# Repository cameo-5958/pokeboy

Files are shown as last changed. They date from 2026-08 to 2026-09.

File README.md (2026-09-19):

# Pokeboy

Game Boy handheld with its own emulator and a Gen 1 Pokemon battle AI that runs
on the device. No ROMs in here, bring your own.

## How the AI works

Trainers are driven by a small transformer with a GRU on top. It is integer
only: int8 weights, int16 hidden state, no floats on the device.

The patched ROM runs an unused opcode (`$DB`, `$EB`, `$EC`) wherever the game
would normally pick a trainer's move. The emulator traps it, reads the battle
out of WRAM, runs the model and writes the choice back.

One decision is too slow for a single frame on the Cortex-A8, so the model is
cut into small steps (one GEMM block, one attention head, one GRU step) and the
scheduler fits them in between frames. `ai/models/pep_int.py` is the reference
and the C++ in `pkai/` has to match it bit for bit. There is a test for that.

## Layout

- `gameboy/` emulator core, tests, tools
- `emulator/` frontends: linux, headless, win32
- `pkai/` battle AI
- `pred-patch/` pokered with the opcodes the AI hooks into
- `ai/` simulator, training, weight export
- `buildroot/` device image (PocketBeagle / OSD3358)
- `hardware/` KiCad project
- `app/` Expo app
- `backend/` API for ROMs, mods and cartridge metadata

## Build

```sh
# core, C++17
cmake -S gameboy -B build -DCMAKE_BUILD_TYPE=Release -DPKAI_BUILD_ROM=OFF
cmake --build build -j
build/gbemu_headless game.gb 1800 out.bmp

# patched ROM (needs rgbds) and AI
pred-patch/build_ai.sh
cd ai && uv sync --group dev && sim/build_engine.sh && scripts/build_pkai.sh

# device image
buildroot/scripts/build-image.sh
buildroot/scripts/qemu/run-system.sh

# backend (:4000) and app
cd backend && npm install && npm run dev
cd app && npm install && npm start
```

Most of the `pkai` tests skip themselves until the patched ROM and the weights
have been built.

## License

MIT, see `LICENSE`. `pred-patch/` is the pret/pokered disassembly under its own
terms, see `pred-patch/THIRD_PARTY_NOTICES.md`.

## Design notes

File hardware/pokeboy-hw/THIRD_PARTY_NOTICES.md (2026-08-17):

# Third-party hardware notice

`Pokeboy.pretty/OSD335X-BGA-256.kicad_mod` is adapted from the PocketBeagle
hardware design published by BeagleBoard.org at
<https://github.com/beagleboard/pocketbeagle>.

PocketBeagle hardware design files are licensed under Creative Commons
Attribution 4.0 International (CC BY 4.0). Pokeboy modifications include the
footprint library name, value, board placement, net assignments, and escape
routing integration.

License: <https://creativecommons.org/licenses/by/4.0/>

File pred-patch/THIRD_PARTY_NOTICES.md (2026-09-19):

# Third-party notice

This directory is the pret/pokered disassembly, <https://github.com/pret/pokered>,
with the Pokeboy AI patch on top: the `$DB`/`$EB`/`$EC` opcodes and
`tools/generate_ai.py`. Everything else is upstream work under pret's terms.

The patch lives mostly in `engine/battle/ai_protocol.asm`, with call sites in
`engine/battle/core.asm`, `trainer_ai.asm` and `used_move_text.asm`, and a few
bytes of state in `ram/wram.asm`. To see all of it:

```sh
git diff a41af38 HEAD -- pred-patch
```

`a41af38` is the untouched upstream import.

The patch itself is MIT, same as the rest of Pokeboy; see `LICENSE` in the
parent repository.

Pokemon is © Nintendo / Creature Inc. / GAME FREAK inc. No ROM is distributed
here; `build_ai.sh` assembles one from this source on your machine.

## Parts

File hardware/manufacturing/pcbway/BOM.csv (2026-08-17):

Item | Qty | Designators | Value | Footprint | Manufacturer | Manufacturer Part Number | Assembly | Substitution note
1 | 1 | U1 | AM3358 + 1GB DDR3L | 21x21mm 256-BGA 1.27mm | Octavo Systems | OSD3358-1G-ISM | SMT BGA | No substitution; PCBWay to source (full turnkey); X-ray
2 | 1 | U2 | 1S Li-ion charger/power path | VQFN-16 | Texas Instruments | BQ24074RGT | SMT | No substitution
3 | 1 | U3 | 5V buck-boost | TPS63802 DLA10 | Texas Instruments | TPS63802DLAR | SMT | No substitution
4 | 1 | U4 | 3.3V buck | WSON-8 | Texas Instruments | TPS62162DSGR | SMT | No substitution
5 | 1 | U5 | LED boost | WSON-6 | Texas Instruments | TPS61165DRVR | SMT | No substitution
6 | 1 | U6 | I2S mono class-D | TQFN-16 | Analog Devices | MAX98357AETE+T | SMT | No substitution
7 | 1 | U7 | USB ESD | DRT-3 (SOT-5X3) 1.0x1.0mm | Texas Instruments | TPD2EUSB30DRTR | SMT | No substitution; DRT-3 land pattern not SOT-23
8 | 1 | J1 | Micro-USB B | 105017 footprint | Molex | 1050170001 | SMT | No substitution
9 | 1 | J9 | microSD push-push | 104031 footprint | Molex | 1040310811 | SMT | No substitution
10 | 4 | SW1 SW2 SW3 SW4 | D-pad tactile | Pokeboy EVQ-P1905M | Panasonic | EVQ-P1905M | SMT | No substitution
11 | 2 | SW5 SW6 | A/B tactile | Pokeboy B3AL-1001P | Omron | B3AL-1001P | SMT | No substitution
12 | 2 | SW7 SW8 | Start/Select tactile | Pokeboy EVQ-P2B02B | Panasonic | EVQ-P2B02B | SMT | No substitution
13 | 1 | Y1 | 24MHz crystal | 5.0x3.2mm 2-pad | CTS | 445A35A24M00000 | SMT | Verify lifecycle; PCBWay to source (full turnkey)
14 | 1 | L1 | 0.47uH | XFL4015 | Coilcraft | XFL4015-471MEC | SMT | No substitution without power review
15 | 1 | L2 | 2.2uH | NRS3012 | Taiyo Yuden | NRS3012T2R2MMGJ | SMT | Equivalent >=1.5A permitted
16 | 1 | L3 | 10uH | LQH43PN | Murata | LQH43PN100M26L | SMT | Equivalent >=1A permitted; 2.80 mm MAX height (Murata JELF243A-0093); low-profile alt Coilcraft XGL4040-103 (2.10 mm max) needs 4.0x4.0 land
17 | 2 | FB1 FB2 | 600ohm at 100MHz | 0402 | Murata | BLM15AG601SN1D | SMT | Equivalent permitted
18 | 1 | D1 | Red LED | 0402 | Lite-On | LTST-C191KRKT | SMT | Equivalent color/current permitted
19 | 1 | D2 | Green LED | 0402 | Lite-On | LTST-C191KGKT | SMT | Equivalent color/current permitted
20 | 1 | D3 | 60V Schottky | SOD-123F | Nexperia | PMEG6010CEH115 | SMT | Equal or better permitted
21 | 1 | C1 | 10nF 16V X7R | 0402 | Murata | GRM155R71C103KA88D | SMT | Equivalent permitted
22 | 5 | C2 C3 C4 C6 C10 | 10uF 10V X5R | 0402 | Murata | GRM155R61A106ME11D | SMT | No lower voltage
23 | 2 | C7 C8 | 22uF 10V X5R | 0402 | Murata | GRM158R61A226ME15D | SMT | MPN corrected: GRM155 case does not exist in 22uF/10V; GRM158 is the 0.8mm-tall 0402 on the same land
24 | 1 | C11 | 22uF 6.3V X5R | 0402 | Murata | GRM158R60J226ME15D | SMT | MPN corrected: GRM155 case not made in 22uF/6.3V; GRM158 tall 0402 | same land
25 | 9 | C5 C9 C12 C15 C21 C25 C26 C27 C105 | 100nF 16V X7R | 0402 | Murata | GRM155R71C104KA88D | SMT | Equivalent permitted
26 | 1 | C13 | 1uF 50V X5R | 0402 | Murata | GRM155R61H105KE11D | SMT | No lower voltage
27 | 1 | C14 | 4.7uF 10V X5R | 0402 | Murata | GRM155R61A475MEAAD | SMT | Equivalent permitted
28 | 1 | C16 | 220nF 10V X7R | 0402 | Murata | GRM155R71A224KA01D | SMT | Equivalent permitted
29 | 1 | C20 | 10uF 6.3V X5R | 0402 | Murata | GRM155R60J106ME15D | SMT | Equivalent permitted
30 | 2 | C22 C23 | 220pF 50V C0G | 0402 | Murata | GRM1555C1H221JA01D | SMT | Equivalent C0G permitted
31 | 1 | C24 | 1uF 10V X5R | 0402 | Murata | GRM155R61A105KE15D | SMT | Equivalent permitted
32 | 2 | C102 C103 | 18pF 50V C0G | 0402 | Murata | GRM1555C1H180JA01D | SMT | Match crystal load calculation
33 | 1 | C106 | 10uF 10V X5R | 0805 | Murata | GRM21BR61A106KE19L | SMT | Equivalent permitted
34 | 1 | R3 | 0ohm | 0402 | Yageo | RC0402JR-070RL | SMT | Was 10k VBUS divider top (Octavo UB1) - now 0ohm link. R1/R2 deleted in PROTO-B1: USB DP/DM are direct connections
35 | 2 | R10 R11 | 2.2kohm 1% | 0402 | Yageo | RC0402FR-072K2L | SMT | Equivalent permitted
36 | 8 | R31 R32 R104 R105 R106 R107 R108 R109 | 10kohm 1% | 0402 | Yageo | RC0402FR-0710KL | SMT | Equivalent permitted
37 | 8 | R12 R13 R17 R18 R20 R21 R23 R26 | 100kohm 1% | 0402 | Yageo | RC0402FR-07100KL | SMT | Equivalent permitted
38 | 1 | R14 | 806kohm 1% | 0402 | Yageo | RC0402FR-07806KL | SMT | Equivalent permitted
39 | 1 | R15 | 91kohm 1% | 0402 | Yageo | RC0402FR-0791KL | SMT | Equivalent permitted
40 | 1 | R16 | 187kohm 1% | 0402 | Yageo | RC0402FR-07187KL | SMT | Equivalent permitted
41 | 1 | R22 | 10ohm 1% | 0402 | Yageo | RC0402FR-0710RL | SMT | Equivalent permitted
42 | 4 | R27 R28 R29 R30 | 33ohm 1% | 0402 | Yageo | RC0402FR-0733RL | SMT | Equivalent permitted
43 | 2 | R33 R102 | 1Mohm 1% | 0402 | Yageo | RC0402FR-071ML | SMT | Equivalent permitted
44 | 1 | R34 | 330kohm 1% | 0402 | Yageo | RC0402FR-07330KL | SMT | Equivalent permitted
45 | 1 | R5 | 1.78kohm 1% | 0402 | Yageo | RC0402FR-071K78L | SMT | Equivalent permitted
46 | 1 | R6 | 3.09kohm 1% | 0402 | Yageo | RC0402FR-073K09L | SMT | Equivalent permitted
47 | 1 | R7 | 3.01kohm 1% | 0402 | Yageo | RC0402FR-073K01L | SMT | Equivalent permitted
48 | 1 | R8 | 46.4kohm 1% | 0402 | Yageo | RC0402FR-0746K4L | SMT | Equivalent permitted
49 | 1 | R19 | 0ohm | 0402 | Yageo | RC0402JR-070RL | DNP | Do not fit
50 | 1 | R9 | 10kohm | 0402 | Yageo | RC0402FR-0710KL | DNP | Do not fit
57 | 1 | R4 | 10kohm | 0402 | Yageo | RC0402FR-0710KL | DNP | Do not fit; was VBUS divider bottom - deleted so USB0_VBUS sees 5 V (Octavo UB1)
51 | 6 | RN1 RN2 RN3 RN4 RN5 RN6 | 4x22ohm | 4x0603 convex | Yageo | YC164-JR-0722RL | SMT | No substitution without SI review
52 | 4 | RN7 RN8 RN9 RN10 | 4x100kohm | 4x0603 convex | Yageo | YC164-JR-07100KL | SMT | Keep exact SYSBOOT pattern
53 | 1 | J5 | 39-pin 0.3mm bottom-contact FFC connector | EA_WF030_39S land pattern | DISPLAY VISIONS | EA WF030-39S | SMT | Board-mounted connector; must be placed by SMT
54 | 1 | J2 | Protected 1S LiPo with 10k NTC | Wire pads | User supplied | USER-SUPPLIED-LIPO-1S-NTC | OFF-BOARD | Polarity and NTC mandatory
55 | 1 | J4 | 8ohm speaker | Wire pads | User supplied | USER-SUPPLIED-8OHM-SPEAKER | OFF-BOARD | Final assembly only
56 | 1 | MICROSD | Validated boot card | microSD | User supplied | USER-SUPPLIED-MICROSD | OFF-BOARD | Program before functional test
58 | 1 | DISPLAY | EA TFT020-23AINN RGB666 TFT panel | 52x36x2.2mm module on 39-pin FFC tail | DISPLAY VISIONS | EA TFT020-23AINN | OFF-BOARD | Mates into J5; final assembly only
59 | 1 | J3 | SPDT slide power switch | Wire pads | User supplied | USER-SUPPLIED-SLIDE-SPDT | OFF-BOARD | Wires to J3 pads at final assembly
60 | 3 | C107 C108 C109 | 22uF 10V X5R | 0805 | Murata | GRM21BR61A226ME44L | SMT | SYS_VOUT bulk bank moved to 0805 for DC-bias headroom vs Octavo ~50uF requirement (Table 2-1)

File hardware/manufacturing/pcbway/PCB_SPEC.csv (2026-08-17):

Field | Value | Order note
Project | Pokeboy PROTO-B1 | OSD3358-1G-ISM 1 GB revision
Order status | RELEASED | PROTO-B1; design-review fixes applied and verified 2026-08-18
Board quantity | 5 | Bare-board first article
Assembly quantity | 2 | Assembly first article
Layers | 4
Dimensions | 79.4 x 119.4 mm | Edge_Cuts centreline; 79.5 x 119.5 is the outer edge
Finished thickness | 0.80 mm | +/-10 percent
Outer copper | 1 oz
Inner copper | 1 oz | Confirmed with PCBWay 2026-08-17
Material | FR-4 | Tg 150 C minimum
Surface finish | ENIG | RoHS
Solder mask | Black | Gang mask relief approved 2026-08-19: PCBWay removes dams under 0.22 mm at fine-pitch IC pads (0.5 mm QFN/WSON and J5 0.3 mm FFC); U1 BGA dams kept; vias stay tented
Silkscreen | White
Minimum trace | 0.15 mm | Narrowest track routed; only 0.15 and 0.40 mm exist
Minimum space | 0.10 mm | Verified by DRC; clean at 0.100 mm and 428 violations at 0.127 mm
PCBWay track/spacing tier | 4/4 mil (0.10 mm) | Forced by spacing; tracks alone would allow 6/6 mil
Minimum via | 0.45 / 0.20 mm | Pad / finished drill
Via annular ring | 0.125 mm | Just under 5 mil; confirm with PCBWay at quote
Drill count | 239 plated / 0 non-plated | 233 vias at 0.20 mm plus 6 through-hole pads
Via treatment | Tented | Except test points
Impedance control | No | Maintain USB pair geometry
Bare-board class | IPC-A-600 Class 2
Assembly class | IPC-A-610 Class 2
BGA inspection | 100 percent X-ray U1 | Images required
Electrical test | Flying probe | Use the supplied IPC-356 netlist
Panelization | PCBWay standard | Do not place tabs at controls or card opening
Gerbers | Released | PROTO-B1 in fab/ and pokeboy-hw-PROTO-B1-gerbers.zip
Assembly side | Top only | All 111 footprints top-side; B.Paste near-empty
Placements | 102 | 111 footprints less 3 DNP and 6 pad-only
Order config | See PCBWAY_ORDER.md | Field-by-field values for the PCBWay quote form

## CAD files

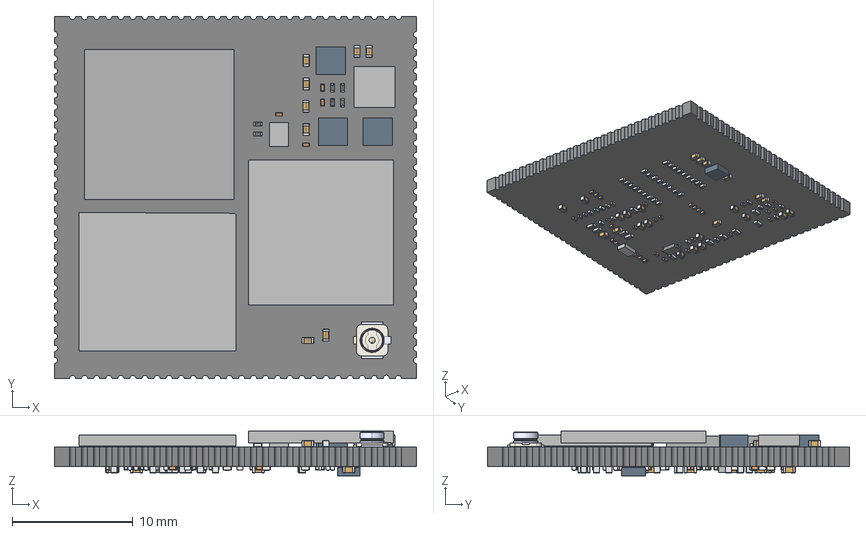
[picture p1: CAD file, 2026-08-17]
hardware/pokeboy-hw/Core1106-3D.stp
30.0 x 30.0 x 3.72 mm
OPEN_CASCADE_STEP_TRANSLATOR_7_
EXTRUDED-9461
USER_LIBRARY-U_FL-R-SMT_10_
USER_LIBRARY-0201_0603M__CAP_1 x 37
USER_LIBRARY-0201_0603M__CAP_2 x 37
USER_LIBRARY-0201_0603M__CAP_3 x 37
3_1_A x 32
SOD323
5_1_2_A x 11
_7_AF0 x 11
EXTRUDED-47948 x 3
USER_LIBRARY-RES_0603-0201_1 x 45
USER_LIBRARY-RES_0603-0201_2 x 45
USER_LIBRARY-RES_0603-0201_3 x 45
USER_LIBRARY-RES_0603-0201_4 x 45
EXTRUDED-53873
EXTRUDED-54088
EXTRUDED-54303
EXTRUDED-54518
EXTRUDED-54737
EXTRUDED-54962

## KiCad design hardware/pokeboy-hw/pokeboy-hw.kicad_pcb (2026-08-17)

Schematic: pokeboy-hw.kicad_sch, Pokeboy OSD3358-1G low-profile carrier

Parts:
C1: 10n; C_0402_1005Metric
C2, C3, C4, C6, C10: 10u/10V; C_0402_1005Metric
C5, C9, C12, C15, C21, C25, C26, C27: 100n; C_0402_1005Metric
C7, C8: 22u/10V; C_0402_1005Metric
C11: 22u/6.3V; C_0402_1005Metric
C13: 1u/50V; C_0402_1005Metric
C14: 4.7u/10V; C_0402_1005Metric
C16: 220n; C_0402_1005Metric
C20: 10u; C_0402_1005Metric
C22, C23: 220p; C_0402_1005Metric
C24: 1u; C_0402_1005Metric
C102, C103: 18pF; C_0402_1005Metric
C105: 100nF; C_0402_1005Metric
C106: 10uF; C_0805_2012Metric
C107, C108, C109: 22u/10V; C_0805_2012Metric
D1: RED CHARGE; LED_0402_1005Metric
D2: GREEN POWER; LED_0402_1005Metric
D3: 60V Schottky; D_SOD-123F; MPN PMEG6010CEH
FB1, FB2: 600R@100MHz; L_0402_1005Metric
J1: USB Micro-B data/power; USB_Micro-B_Molex-105017-0001; MPN Molex 105017-0001
J2: LiPo 1S + / NTC / -; BATTERY_PADS_3
J3: POWER SWITCH PADS; SWITCH_PADS_2
J4: 8 OHM SPEAKER PADS; SPEAKER_PADS_2
J5: EA WF030-39S; EA_WF030_39S; MPN EA TFT020-23AINN + EA WF030-39S
J6: UART TEST PADS; TEST_PADS_3
J7: RECOVERY SHORT PADS; SHORT_PADS_2
J8: RESET SHORT PADS; SHORT_PADS_2
J9: 104031-0811; microSD_HC_Molex_104031-0811
L1: 0.47uH XFL4015; XFL4015; MPN XFL4015-471ME
L2: 2.2uH >1.5A; L_APV_ANR3012; MPN XFL3012-222MEB
L3: 10uH 1A; LQH43PN; MPN LQH43PN100MR0L
R3: 0R; R_0402_1005Metric
R4: 10k; R_0402_1005Metric; not fitted
R5: 1.78k 1%; R_0402_1005Metric
R6: 3.09k 1%; R_0402_1005Metric
R7: 3.01k 1%; R_0402_1005Metric
R8: 46.4k 1%; R_0402_1005Metric
R9: 10k DNP; R_0402_1005Metric; not fitted
R10, R11: 2.2k; R_0402_1005Metric
R12, R13, R18, R20, R21, R23, R26: 100k; R_0402_1005Metric
R14: 806k 1%; R_0402_1005Metric
R15: 91k 1%; R_0402_1005Metric
R16: 187k 1%; R_0402_1005Metric
R17: 100k 1%; R_0402_1005Metric
R19: 0R DNP; R_0402_1005Metric; not fitted
R22: 10R 1%; R_0402_1005Metric
R27, R28, R29, R30: 33R; R_0402_1005Metric
R31, R32, R104, R105, R106, R107, R108, R109: 10k; R_0402_1005Metric
R33: 1M 1%; R_0402_1005Metric
R34: 330k 1%; R_0402_1005Metric
R102: 1M; R_0402_1005Metric
RN1, RN2, RN3, RN4, RN5, RN6: 4x22R; R_Array_Convex_4x0603
RN7, RN8, RN9, RN10: 100k; R_Array_Convex_4x0603
SW1, SW2, SW3, SW4: EVQ-P1905M
SW5, SW6: B3AL-1001P
SW7, SW8: EVQ-P2B02B
U1: OSD3358-1G-ISM; OSD335X-BGA-256
U2: BQ24074RGT; VQFN-16-1EP_3x3mm_P0.5mm_EP1.6x1.6mm; MPN BQ24074RGT
U3: TPS63802DLAR; TPS63802_DLA10; MPN TPS63802DLAR
U4: TPS62162DSG; WSON-8-1EP_2x2mm_P0.5mm_EP0.9x1.6mm_ThermalVias; MPN TPS62162DSGR
U5: TPS61165DRV; WSON-6-1EP_2x2mm_P0.65mm_EP1x1.6mm; MPN TPS61165DRVR
U6: MAX98357AETE+T; TQFN-16-1EP_3x3mm_P0.5mm_EP1.23x1.23mm
U7: TPD2EUSB30; Texas_DRT-3; MPN TPD2EUSB30DRTR
Y1: 24 MHz; CRYSTAL_5X3.2MM

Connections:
/ADC_VREFN: U1.A9 (AGND_ADC), U1.B9 (VREFN)
/ADC_VREFP: U1.A7 (SYS_ADC_1P8V), U1.B7 (VREFP)
/AMP_EN: R26.1, U1.B4 (XDMA_EVENT_INTR1), U6.4 (SD_MODE)
/AMP_OUT_N: FB2.1, U6.10 (OUTN)
/AMP_OUT_P: FB1.1, U6.9 (OUTP)
/BAT_NTC: J2.2, R9.1, U2.1 (TS)
/BAT_PLUS: C3.1, J2.1, R33.1, U2.2 (BAT), U2.3 (BAT)
/BAT_SENSE: C27.1, R33.2, R34.1, U1.A8 (AIN0)
/BB_EN: R16.2, R17.1, U3.1
/BB_FB: R14.2, R15.1, U3.4
/BB_L1: L1.1, U3.9
/BB_L2: L1.2, U3.7
/BB_MODE: R19.2, R20.1, U3.2
/BB_PG: R18.2, U3.5
/BL_COMP: C16.1, U5.2 (COMP)
/BL_CTRL: R23.1, U1.C3 (MCASP0_AXR1), U5.5 (CTRL)
/BL_SW: D3.1 (K), L3.2, U5.4 (SW)
/BQ_ILIM: R6.1, U2.12 (ILIM)
/BQ_ISET: R5.1, U2.16 (ISET)
/BQ_ITERM: R7.1, U2.15 (ITERM)
/BQ_TMR: R8.1, U2.14 (TMR)
/BTN_A: SW6.1, U1.A13 (SPI0_SCLK)
/BTN_B: SW5.1, U1.A14 (SPI0_CS0)
/BTN_DOWN: SW3.1, U1.A11 (UART1_RXD)
/BTN_LEFT: SW1.1, U1.A3 (MCASP0_ACLKR)
/BTN_RIGHT: SW4.1, U1.A4 (XDMA_EVENT_INTR0)
/BTN_SELECT: SW7.1, U1.B1 (MCASP0_AHCLKR)
/BTN_START: SW8.1, U1.B3 (MCASP0_FSR)
/BTN_UP: SW2.1, U1.A10 (UART1_RTSN)
/BUCK_PG: R21.2, U4.8 (PG)
/BUCK_SW: L2.1, U4.7 (SW)
/CHG_ACTIVE_N: D1.2 (A), R12.2, U1.C13 (UART0_RTSN), U2.9 (~CHG)
/CHG_PGOOD_N: D2.2 (A), R13.2, U1.R7 (GPMC_CSN3), U2.7 (~PGOOD)
/I2S_BCLK: U1.A1 (MCASP0_ACLKX), U6.16 (BCLK)
/I2S_DOUT: U1.B2 (MCASP0_AXR0), U6.1 (DIN)
/I2S_LRCLK: U1.A2 (MCASP0_FSX), U6.14 (LRCLK)
/JTAG_TDI: J7.1, U1.C1 (TDI)
/LCD_CLK_CORE: RN5.3 (R3.1), U1.F1 (LCD_PCLK)
/LCD_CLK_FPC: J5.23, RN5.6 (R3.2)
/LCD_D0_CORE: RN1.1 (R1.1), RN10.8 (R1.2), U1.G3 (LCD_DATA0)
/LCD_D0_FPC: J5.5, RN1.8 (R1.2)
/LCD_D1_CORE: RN1.2 (R2.1), RN10.7 (R2.2), U1.G2 (LCD_DATA1)
/LCD_D1_FPC: J5.6, RN1.7 (R2.2)
/LCD_D2_CORE: RN1.3 (R3.1), RN10.6 (R3.2), U1.G1 (LCD_DATA2)
/LCD_D2_FPC: J5.7, RN1.6 (R3.2)
/LCD_D3_CORE: RN1.4 (R4.1), RN10.5 (R4.2), U1.H3 (LCD_DATA3)
/LCD_D3_FPC: J5.8, RN1.5 (R4.2)
/LCD_D4_CORE: RN2.1 (R1.1), RN9.4 (R4.1), U1.H2 (LCD_DATA4)
/LCD_D4_FPC: J5.9, RN2.8 (R1.2)
/LCD_D5_CORE: RN2.2 (R2.1), RN9.3 (R3.1), U1.H1 (LCD_DATA5)
/LCD_D5_FPC: J5.10, RN2.7 (R2.2)
/LCD_D6_CORE: RN2.3 (R3.1), RN9.2 (R2.1), U1.J3 (LCD_DATA6)
/LCD_D6_FPC: J5.11, RN2.6 (R3.2)
/LCD_D7_CORE: RN2.4 (R4.1), RN9.1 (R1.1), U1.J2 (LCD_DATA7)
/LCD_D7_FPC: J5.12, RN2.5 (R4.2)
/LCD_D8_CORE: RN3.1 (R1.1), RN8.4 (R4.1), U1.J1 (LCD_DATA8)
/LCD_D8_FPC: J5.13, RN3.8 (R1.2)
/LCD_D9_CORE: RN3.2 (R2.1), RN8.3 (R3.1), U1.K3 (LCD_DATA9)
/LCD_D9_FPC: J5.14, RN3.7 (R2.2)
/LCD_D10_CORE: RN3.3 (R3.1), RN8.2 (R2.1), U1.K2 (LCD_DATA10)
/LCD_D10_FPC: J5.15, RN3.6 (R3.2)
/LCD_D11_CORE: RN3.4 (R4.1), RN8.1 (R1.1), U1.K1 (LCD_DATA11)
/LCD_D11_FPC: J5.16, RN3.5 (R4.2)
/LCD_D12_CORE: RN4.1 (R1.1), RN7.4 (R4.1), U1.L3 (LCD_DATA12)
/LCD_D12_FPC: J5.17, RN4.8 (R1.2)
/LCD_D13_CORE: RN4.2 (R2.1), RN7.3 (R3.1), U1.L2 (LCD_DATA13)
/LCD_D13_FPC: J5.18, RN4.7 (R2.2)
/LCD_D14_CORE: RN4.3 (R3.1), RN7.2 (R2.1), U1.L1 (LCD_DATA14)
/LCD_D14_FPC: J5.19, RN4.6 (R3.2)
/LCD_D15_CORE: RN4.4 (R4.1), RN7.1 (R1.1), U1.M3 (LCD_DATA15)
/LCD_D15_FPC: J5.20, RN4.5 (R4.2)
/LCD_D16_CORE: RN5.1 (R1.1), U1.P7 (GPMC_AD15)
/LCD_D16_FPC: J5.21, RN5.8 (R1.2)
/LCD_D17_CORE: RN5.2 (R2.1), U1.T6 (GPMC_AD14)
/LCD_D17_FPC: J5.22, RN5.7 (R2.2)
/LCD_DE_CORE: RN5.4 (R4.1), U1.E1 (LCD_AC_BIAS_EN)
/LCD_DE_FPC: J5.24, RN5.5 (R4.2)
/LCD_HSYNC_CORE: RN6.1 (R1.1), U1.F2 (LCD_HSYNC)
/LCD_HSYNC_FPC: J5.25, RN6.8 (R1.2)
/LCD_VSYNC_CORE: RN6.2 (R2.1), U1.F3 (LCD_VSYNC)
/LCD_VSYNC_FPC: J5.26, RN6.7 (R2.2)
/LED_A: C13.1, D3.2 (A), J5.2
/LED_CHG_A: D1.1 (K), R10.2
/LED_K: J5.1, R22.1, U5.1 (FB)
/LED_PG_A: D2.1 (K), R11.2
/NPOR: J8.1, R32.2, U1.R11 (WARMRSTN)
/OSD_1V8: U1.F10 (SYS_VDD_1P8V), U1.G10 (SYS_VDD_1P8V), U1.H10 (SYS_VDD_1P8V), U1.H11 (SYS_VDD_1P8V), U1.J10 (SYS_VDD_1P8V), U1.J11 (SYS_VDD_1P8V), U1.K10 (SYS_VDD_1P8V), U1.L10 (SYS_VDD_1P8V)
/OSD_3V3A: J9.4, R12.1, R13.1, R18.1, R32.1, R104.2, R105.2, R106.2, R107.2, R108.2, R109.2, U1.F8 (SYS_VDD3_3P3V), U1.F9 (VDDSHV4), U1.G8 (SYS_VDD3_3P3V), U1.G9 (VDDSHV5), U1.H7 (SYS_VDD3_3P3V), U1.H8 (SYS_VDD3_3P3V), U1.H9 (VDDSHV6), U1.J7 (SYS_VDD3_3P3V), U1.J8 (SYS_VDD3_3P3V), U1.J9 (VDDSHV1), U1.K8 (SYS_VDD3_3P3V), U1.K9 (VDDSHV2), U1.L8 (SYS_VDD3_3P3V), U1.L9 (VDDSHV3)
/OSD_3V3AUX: U1.F11 (SYS_VDD2_3P3V), U1.G11 (SYS_VDD2_3P3V)
/OSD_3V3B: C105.1, RN7.7 (R2.2), RN9.5 (R4.2), RN10.4 (R4.1), U1.F6 (SYS_VDD1_3P3V), U1.F7 (SYS_VDD1_3P3V), U1.G6 (SYS_VDD1_3P3V), U1.G7 (SYS_VDD1_3P3V)
/OSD_OSC_IN: C102.1, R102.1, U1.P16 (OSC0_IN), Y1.2
/OSD_OSC_OUT: C103.1, R102.2, U1.N16 (OSC0_OUT), Y1.1
/OSD_RTC_1V8: U1.K11 (SYS_RTC_1P8V), U1.L11 (SYS_RTC_1P8V)
/OSD_SYS: C107.1, C108.1, C109.1, U1.K6 (SYS_VOUT), U1.K7 (SYS_VOUT), U1.L6 (SYS_VOUT), U1.L7 (SYS_VOUT)
/PMIC_PGOOD: U1.N12 (PMIC_PGOOD), U1.P11 (PWRONRSTN)
/PMIC_PWR_EN: U1.N10 (PMIC_POWER_EN), U1.N11 (PMIC_PWR_EN)
/PWR_SW: J3.2, R16.1
/RTC_PWRONRSTN: U1.N4 (PMIC_LDO_PGOOD), U1.N5 (RTC_PWRONRSTN)
/SD_CD_N: J9.9, R109.1, U1.C14 (SPI0_CS1)
/SD_CLK: J9.5, U1.B15 (MMC0_CLK)
/SD_CMD: J9.3, R108.1, U1.B16 (MMC0_CMD)
/SD_D0: J9.7, R104.1, U1.A16 (MMC0_DAT0)
/SD_D1: J9.8, R105.1, U1.A15 (MMC0_DAT1)
/SD_D2: J9.1, R106.1, U1.C16 (MMC0_DAT2)
/SD_D3: J9.2, R107.1, U1.C15 (MMC0_DAT3)
/SPK_N: C23.1, FB2.2, J4.2
/SPK_P: C22.1, FB1.2, J4.1
/SYS_5V: C7.1, C8.1, C9.1, C10.1, C14.1, C15.1, C20.1, C21.1, C106.1, L3.1, R14.1, U1.P10 (VIN_AC), U1.R10 (VIN_AC), U1.T10 (VIN_AC), U3.6, U4.2 (VIN), U4.3 (EN), U5.6 (VIN), U6.7 (VDD), U6.8 (VDD)
/SYS_BAT: C4.1, C6.1, J3.1, R10.1, R11.1, U2.10 (OUT), U2.11 (OUT), U3.10
/TFT_DC: J5.32, R29.2
/TFT_DC_CORE: R29.1, U1.C5 (ECAP0_IN_PWM0_OUT)
/TFT_RESET: J5.33, R30.2, R31.2
/TFT_RESET_CORE: R30.1, U1.C12 (UART0_CTSN)
/TFT_SCL: J5.31, R27.2
/TFT_SCL_CORE: R27.1, U1.C10 (I2C0_SCL)
/TFT_SDA: J5.29, R28.2
/TFT_SDA_CORE: R28.1, U1.C11 (I2C0_SDA)
/UART0_RX: J6.2, U1.A12 (UART0_RXD)
/UART0_TX: J6.1, U1.B12 (UART0_TXD)
/USB_DM: J1.2 (D-), U1.K16 (USB0_DM), U7.2 (D-)
/USB_DP: J1.3 (D+), U1.K15 (USB0_DP), U7.1 (D+)
/USB_VBUSDET: C1.1, R3.2, R4.1, U1.J16 (USB0_VBUS)
/VIN_BAT: U1.N7 (PMIC_BAT_SENSE), U1.P8 (VIN_BAT), U1.R8 (VIN_BAT), U1.T8 (VIN_BAT)

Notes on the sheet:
DESIGN INTENT: panel covers the 30x30 mm Core1106; the carrier aperture clears underside parts. The modelled top envelope is about 2.6 mm, leaving ~0.6 mm nominal in a 3.2 mm cavity. Specify inside-corner radius <=0.75 mm and validate solder standoff, display fit, and thermals on first article.
DISPLAY FIRMWARE: RGB666 data D0-D17 plus CLK/DE/HSYNC/VSYNC. ST7789V serial setup uses SDA/SCL/D-C/RESET; RGB-mode CS and TE are intentionally not connected. Initial timing target: ~17 MHz pixel clock, HS 30/HBP 30/HFP 60, VS 4/VBP 4/VFP 8; validate against the exact panel lot.

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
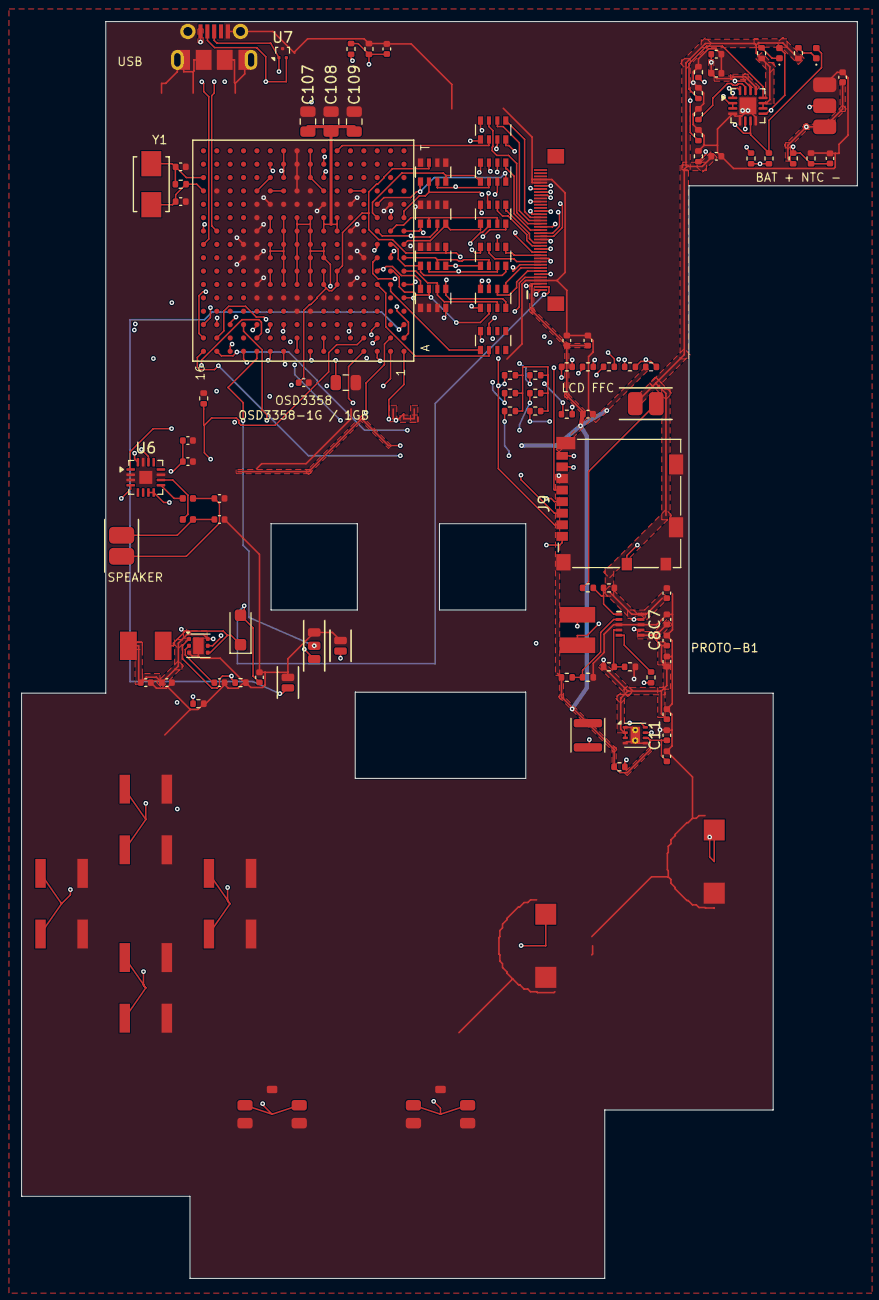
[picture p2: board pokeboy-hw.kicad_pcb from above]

Board: 4 copper layers, 79.4 x 119.4 mm, 111 parts (0 on the bottom side), 126 nets.

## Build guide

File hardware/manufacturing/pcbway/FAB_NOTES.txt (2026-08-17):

POKEBOY OSD3358-1G CARRIER - PROTO-B1 / RELEASED FOR FABRICATION

ORDER STATUS
- RELEASED FOR FABRICATION 2026-08-18 as PROTO-B1. 5-board bare PCB, 2-board
  assembly. All design-review findings fixed: U7 on DRT-3 and re-routed, J5
  connector placed and in BOM/CPL, J5 pin 35 IM3 strap = VDD (RGB mode), BQ24074
  EN1 on VBUS (batteryless USB boot in USB500), USB D+/D- continuous (R1/R2
  removed), SYS_VOUT bulk = 3x 22 uF 0805, capacitor MPNs corrected to real
  Murata parts, MSL 4 handling stated. DRC/ERC: zero errors, zero warnings.
- Accepted limitations for this prototype, by design: no JTAG beyond the TDI
  pad (J7, net JTAG_TDI); no USB impedance control (short trace lengths).
- Connectivity is complete: DRC reports 0 errors, 0 warnings and 0 unconnected
  items, with no
  shorts or spacing violations, ERC reports 0 errors, and the schematic netlist
  matches the board connectivity net for net. The microSD pull-up branches,
  the AUX_3V3 rail, SYS_5V stitching and the isolated ground-pour islands are all
  closed.
- U1's ball map was checked against Octavo's PocketBeagle reference design. Four
  balls that reference ties had been left floating and are now connected:
  PMIC_POWER_EN/PMIC_PWR_EN, PMIC_LDO_PGOOD/RTC_PWRONRSTN, PMIC_PGOOD/PWRONRSTN,
  and the ADC reference pair feeding the battery-sense input. The PMIC enable was
  among them, so the previous revision would not have powered up.
- Octavo's paid design review is intentionally not purchased. Octavo's own
  OSD335x schematic checklist was executed item by item instead; every mandatory
  item is closed on the board (SYS_VOUT bulk capacitance, ground stitching,
  VIN_BAT/PMIC_BAT_SENSE and VIN_USB ties, EEPROM_WP). PCBWay confirmed the
  0.125 mm annular ring on 2026-08-18; the 5-board first article serves as the
  physical design review.

Board construction
- 0.80 mm finished thickness, four copper layers, ENIG finish.
- Nominal stack: 0.10 mm outer prepreg / 0.44 mm core / 0.10 mm outer prepreg.
- Minimum routed trace 0.10 mm at the display breakout; default signal trace 0.15 mm.
- Minimum copper clearance 0.10 mm; minimum solder-mask web 0.05 mm.
- Through via 0.45 mm finished pad diameter / 0.20 mm drill.

Critical mechanical instruction
- U1 is a direct-mounted 21 x 21 x 2 mm, 1.27 mm-pitch BGA; the former Core1106
  underside aperture is closed.
- Use X-ray inspection for U1 and verify voiding/bridging against IPC-A-610 Class 2.
- A 3.2 mm cavity leaves approximately 1.2 mm nominal allowance above U1, but U1
  is NOT the binding part. L3 (Murata LQH43PN100M26L) is 2.6 mm +/-0.2 per the
  Murata reference spec JELF243A-0093, i.e. 2.80 mm MAX, and SW7, SW8 and J1
  are all above 2.4 mm. A flat 3.2 mm cavity therefore clears L3 by only
  0.40 mm at the datasheet maximum. Size the cavity to 2.80 mm, or step it, or
  substitute a lower inductor (Coilcraft XGL4040-103 is 2.10 mm max, Isat
  1.4 A, DCR 46 mOhm - better in every axis but needs a 4.0 x 4.0 mm land
  pattern). See height-map.svg for the full profile.
- The six face buttons stand 5.00 mm above the board and are intended to
  protrude through the enclosure face; they are not a cavity constraint.
- U1 (Octavo OSD335x-SM) is MSL 4, confirmed in the OSD335x-SM datasheet Rev. 12
  ("These devices are susceptible to moisture and are classified as MSL 4"):
  keep in dry pack
  until placement, honour the floor life, and bake per J-STD-033 if it is
  exceeded. Peak reflow per the OSD335x datasheet, not a generic profile.
- Build and measure a first article before committing the display carrier/enclosure.

Assembly and validation
- U1 is OSD3358-1G-ISM (1 GB DDR3L); boot media is J9 microSD 104031-0811.
- U6 is MAX98357AETE+T I2S mono class-D audio; no analog codec line-out is used.
- J1 is Micro-USB data plus charge, not charge-only.
- Battery is a protected 1S LiPo with 10 kohm NTC.
- Validate sustained-load temperature, charger operation, USB data, display timing,
  backlight current, audio, and every control input before enclosing the first article.
- U1 is rendered as its 21 x 21 mm package envelope; generic component bodies
  require the standard KiCad 9 3D model library on the viewing workstation.

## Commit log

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2026-07-04 apu: implement all four sound channels
    Pulse x2 (sweep on ch1), wave, noise; 512 Hz frame sequencer; NR5x
    mixing; 44.1 kHz stereo float ring buffer drained by the frontend.
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2026-07-07 win32: fix layout jitter — proper screen scaling between controls + hysteresis
2026-07-07 win32: fix DC corruption — deselect GDI brushes before deleting in draw_button
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2026-07-09 custom music: key tracks on the game's song id, keep native SFX audible
    Map-byte polling started tracks before the game played music (title
    screen got Pallet Town) and overriding muted all native audio including
    sound effects. Now the resolver follows the gen 1 sound engine's current
    song (wChannelSoundIDs/wAudioROMBank), covering the full soundtrack:
    title, battles, victories, surf, bike, jingles and every area, with
    wCurMap refining songs the game reuses across places. A new APU output
    mask (gb_set_audio_mask) mutes only the music channels while a custom
    track plays, passing through channels the engine assigns to SFX, so
    effects, cries and jingles play over the replacement music. Unmapped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
2026-07-10 feat(backend): registry, device API keys, and settings-driven backend URL
    Backend:
    - Relocate ROM/mod/label/registry storage to config-driven dirs
    (roms/, mods/, labels/, data/registry.json); all paths declared in config.ts.
    - Add unified GET /api/registry (roms + mods with versions and live checksums).
    - Add Pokemon Red to the registry.
    - Device API key system: keystore (data/keys.json), `npm run key:new|list|revoke`,
    admin-guarded POST/GET/DELETE /api/keys, and an x-api-key guard that
    auto-activates once a key has been issued.
    App:
    - Persist settings (backend URL + API key) locally via AsyncStorage, shared
    app-wide through a SettingsProvider context.
    - Route the whole app through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
2026-07-11 fix(emulator): port web run-loop/audio/save architecture into mobile embed
    Fixes accumulating speed-swap slowdown (unbounded frame accumulator),
    audio drift at non-1x speeds, save corruption on background/kill, and
    session memory growth. Ports the proven index.html loop, audio pipeline,
    and save cadence into embed.html; adds a nonce-guarded AsyncStorage save
    mirror, foreground audio recovery, WebView process-death reload, and
    IndexedDB handle leak fixes on the app side.
2026-07-11 feat: opt-in telemetry with tailnet MCP access, registry cleanup, eject and label fixes
    - Telemetry: settings toggle (default off) streams 1 Hz emulator vitals
    (fps, accumulator, audio state/backlog, heap) to the backend; in-memory
    session store exposed via MCP server bound to the Tailscale address
    (pokeboy-telemetry at :4141/mcp). Off means zero collection.
    - Registry cleanup: backend destroys ROM/mod/label/symbol files no longer
    referenced by the registry (startup + registry watch, guarded against
    empty/broken registries); emulator page evicts stale IndexedDB entries.
    - Pokemon Blue/Yellow fully wiped from registries, carts, and labels.
    - Eject now exits the game immediately: sav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
2026-07-11 feat: dev-mode remote control via MCP; fix iOS labels, stale caches, input lockup
    Dev mode (opt-in settings toggle):
    - App polls /api/dev/commands (750ms) and posts results; remote presses
    OR-merge with physical input. Embed answers dev-frame requests with a
    PNG of the 160x144 LCD framebuffer (OS screenshots render the WebView
    black). Backend queues commands per device with 15s result timeouts.
    - Tailnet MCP server gains dev_status, dev_press (a/b/start/select/dpad
    + hold_ms) and dev_screenshot (returns an image content block).
    Fixes:
    - Backend trusts the loopback proxy (X-Forwarded-Proto) so label/ROM URLs
    come out https:// via pokeboy.cameo.moe — iOS ATS silently blocked the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
2026-07-12 bugf(app): whitelist file:// origins for the emulator WebView
    react-native-webview's default originWhitelist is http/https only, so the
    locally bundled embed.html's file:// URI was silently blocked (shouldStart
    =false, console.warn only) — a blank WebView with no error callback. This
    is why the local emulator never booted on device while remote builds did.
2026-07-12 bugf(app): surface emulator bootstrap failures instead of dying silently
    The embed.html bootstrap IIFE throws for a missing PokeboyRuntime and
    rejects when the gbcore/mod-core script tags fail to load — all before
    reportError exists, so failures vanished as unhandled rejections. Catch
    the IIFE promise, show the message in the status element, and post an
    error event (stage: bootstrap) to the host so it reaches telemetry.
    Also name the failing URI in loadScript errors.
2026-07-12 bugf(app): hand wasm bytes to the emulator instead of fetching file:// URIs
    WKWebView's Fetch API cannot load file:// URLs, so the Emscripten glue's
    fetch of gbcore.wasm failed with TypeError: Load failed at wasm-initialize
    even once the document itself loaded. Read the wasm as base64 on the native
    side (expo-file-system) and pass it through PokeboyRuntime so createGBCore
    gets Module.wasmBinary and never fetches; the locateFile fallback remains
    for hosted (http) use.
2026-07-12 mod(cable-club): pass tradeback bank in b so the receptionist hook works
    The CableClubNPC hook loaded the target bank with ld a,$12, but home Bankswitch
    reads the bank from register b (ld a,b). It bank-switched to a garbage bank and
    jumped into wrong-bank code. Change to ld b,$12 (3e 12 -> 06 12). Bump 1.2.0 -> 1.2.1.
2026-07-12 bugf(backend): bump tradeback-npc registry version to 1.2.1
    The registry version is the client cache key (mod:<id>@<version>); evictStaleCache
    keys on it, not the payload checksum. It still read 1.2.0 after the mod was rebuilt,
    so clients kept serving the stale cached payload and the CableClubNPC patch never
    reached the ROM. Align the registry with the shipped mod (1.2.1) to bust the cache.
2026-07-12 feat(battle-link): configurable maxTimeTillRandom with frame-driven failsafe
    Replace the hardcoded 30s decision deadline with a maxTimeTillRandom
    setting (seconds, default 30, 0 = instant random with no request),
    configured on the mod config screen and injected as
    battleLinkMaxTimeTillRandomMs; the snapshot's timeoutMs advertises it.
    Enforce the deadline from the per-frame decide() poll as well: on a
    device the decision GET never left the WebView and the async fallback
    timer never fired, freezing battles indefinitely. The ROM polls decide
    every frame, so checking pending.deadline there guarantees recovery even
    with a wedged fetch. Emit PokeboyModEvent breadcrumbs (fetch-start,
    fetch-error,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
2026-07-12 feat: DMG-style boot screen in emulator embed
    Replace the static LOADING overlay with a Game Boy-style power-on
    sequence drawn on the LCD canvas: the POKEBOY logo steps down the
    screen, the classic two-tone chime (~1048 Hz then ~2080 Hz square
    wave) rings when it lands, and a glint sweeps across the letters.
    The sequence plays while the core/ROM/mods load behind it, and
    boot() holds the first game frame until it finishes. Errors cancel
    the animation and restore the status overlay. The chime routes
    through the AudioSystem master gain so mute/volume settings apply.
2026-07-12 bugf(app): persist enabled mod toggles across app relaunches
    enabledMods was session-only React state, so every relaunch silently
    reset all mod toggles to OFF and battles ran the native AI — which
    looked like Battle Link deciding instantly. Store the enabled set in
    AsyncStorage and restore it on mount.
2026-07-12 feat(boot): in-emulator Pokeboy logo boot with glint and chime at 60fps
    Replace the 6fps video-slideshow boot ROM content with a generated
    Pokeboy wordmark: palette fade-in, DMG-style two-note chime, and a
    glint sweep across the logo. The boot ROM engine is now a data-driven
    copy-list interpreter; each frame only rewrites the tiles the glint
    band crosses, eliminating the full-VRAM redraw that caused the lag.
    Boot ROM shrinks from 1.1MB to 32KB and the wasm core from 259KB to
    199KB. Reverts the JS canvas boot overlay in embed.html — the boot is
    CPU-executed inside the core.
2026-07-12 bugf(core): rewire cpu.mods after the custom-boot reset so D3 host traps fire
    gb_load_rom() wires cpu.mods in load_rom(), then immediately calls
    reset_custom_boot(), which rebuilds the CPU (cpu = CPU{}) and restores
    cpu.bus but not cpu.mods. Every embed session boots through exactly this
    path (gb_reset_post_boot is not even exported to the wasm build), so the
    0xD3 host-call trap dispatched against a null mods pointer and silently
    degraded to the illegal-opcode NOP: mods loaded, linked, and patched, but
    no host import ever ran on a device.
    This is the root cause of both Battle Link field failures:
    - 1.0.1 "wedge": the dead trap preserved A=0, which the shim read as
    "pending" forever (no fe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
2026-07-12 test(mods): update tradeback post-load bytes for the ld b,$12 hook
    452330e changed the CableClubNPC hook's first instruction from ld a,$12
    to ld b,$12 but left this hard-coded expectation on the old byte. The
    package itself loads and patches correctly; only the fixture was stale.
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2026-07-13 fix(ai): correct engine order-array semantics in battle facade
    _active_ix searched for the party mon at slot 1 instead of reading
    order[0], and switch actions mapped engine positions rather than the
    schema_v1 bench-listing contract — both silently wrong once switches
    permute the order array (79% of mid-battle switches misdirected).
2026-07-13 bugf(battle-link): no B-cancel once the turn is committed (1.0.7)
    A switch or item spends the player's turn before SelectEnemyMove runs,
    and the cancel path restarts the battle menu without undoing it, so B
    during AWAITING refunded committed switches/items indefinitely. Gate the
    cancel poll on wActionResultOrTookBattleTurn and blank the hint row when
    the turn is spent.
2026-07-13 feat(battle-link): discord decision source with phone-hosted bot
    Adds a second way Battle Link decisions are made. A GET | DISC selector
    in the mod config picks the source:
    - GET (existing): poll the configured public HTTPS endpoint.
    - DISC: a minimal Discord bot (gateway v10 + REST, zero dependencies)
    runs inside the app itself; the token lives in the device keychain
    via expo-secure-store and never enters the WebView.
    The bot registers /connect and /disconnect as user-installable app
    commands (usable anywhere). /connect binds the invoking channel to the
    current battle and is deliberately left unacknowledged when no battle
    is active. Every decision poll posts an embed with the battle s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
2026-07-13 feat(battle-link): defer switch/item execution until the decision arrives (1.0.8)
    Two new pre-commit hooks patch the moment before a committed action runs:
    UseBagItem's `call UseItem` and the `call GBPalNormal` that falls into
    SwitchPlayerMon. Both run the (cancellable) AWAITING wait there, so B backs
    out with nothing spent and the mon/item only commits once the host answers.
    The resolved decision is stashed in the link-battle RNG list tail
    ($d14f-$d151, idle in non-link battles) because wBuffer aliases the HP-bar
    animation scratch — this also fixes enemy item/switch decisions being
    clobbered by damage animations on player-first turns.
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2026-07-13 fix(battle-link): one edited Discord widget, ack-first clicks, free switching
    Telemetry from the on-device test showed the three failure chains:
    - Component callbacks 404'd (10062) because the ack was sent after other
    work and after gateway-resume replays, so Discord flagged working clicks
    as "This interaction failed". Interactions are now acknowledged (type 6)
    before anything else, /connect and /disconnect always answer (ephemeral
    when declining), and a failed ack still delivers the decision.
    - A user-installed app has no channel access (403 Missing Access), and the
    webhook fallback died with the un-acked token (10015), stalling polls
    from turn ~3 into random fallbacks. The ses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
2026-07-13 feat(ai): emit schema_v1 history_tail from showdown and metamon converters
    Showdown replays get the full SPECS §4.1 tail — last 20 turns of
    (my_action, opp_action, damage buckets, event flags) flipped per
    perspective; metamon parsed states only carry prev-move fields, so
    they get a K=1 action-only tail with unknowns as null.
2026-07-13 feat(ai): HIST segment — tokenizer encoding, live-sim tracking, trainer flag
    Tokenizer(hist_k=20) appends 5 tokens per remembered turn (actions,
    damage buckets, priority event) on HIST_-k turn-offset slots, seq 256;
    hist_k=0 reproduces the legacy encoding so old checkpoints still load
    (checkpoints now carry hist_k/seq_len). battle.py builds tails from
    engine-observable diffs only — opponent chosen-but-blocked moves stay
    hidden (recharge-quirk tested).
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2026-07-13 chore(app): bump build stamp to 0.2.1 so the widget-fix build is verifiable on device
    The 2026-07-13 16:51 retest telemetry shows the pre-fix bundle still
    running (channel 403 retried per turn, dead un-acked token chained into
    the followup) — but both builds stamp 0.2.0, so the on-screen BUILD line
    could not prove it. 0.2.1 = the single-widget/ack-first/free-switching
    code from PR #27.
2026-07-13 fix(ai): decision-boundary snapshots in showdown converter; clear stale parts
    Remediates workspace/AI-DATA.md criticals: normal-turn rows now snapshot
    at the turn boundary (both players see one pre-effect state; verified no
    same-turn reveals/hp cross perspectives), first-use moves and unrevealed
    switch targets are unrecoverable and no longer emitted (fixture: 84→49
    rows, label-in-input leak 52%→0, absent switch targets 10→0), and
    showdown/pokechamp conversion clears part files before rewriting.
    Forced replacements keep execution-time state by design.
2026-07-13 fix(battle-link): remote faint switch-ins, validated send-out slots, turn-start requests, tight AWAITING box (mod 1.3.0, stamp 0.2.3)
    - EnemySendOut freeze: the patched candidate scan returned the first
    non-current slot with no HP check, and the ROM's own fainted-mon check
    loops back INTO the patched bytes without advancing the slot — an
    infinite loop once any benched mon had fainted (always by the time the
    enemy was down to its last mon). Every slot leaving
    BattleLinkChooseSwitch is now bounds/on-field/HP validated.
    - Forced switch-ins after an enemy faint now poll the decision source
    (trap status 6) with switch-only legal actions; the battle-opening
    send-out is told apart h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
2026-07-14 feat(ai): rich 20-turn metamon history tails + train-time tail augmentation
    Ablation showed dense live tails degrade play (89%→59.5% vs random)
    because 82% of rows carried K=1 stub tails. Metamon trajectories are
    sequential, so real tails are reconstructible: own actions from the
    actions array, opp actions from prev_move/species diffs, damage buckets
    from hp deltas, KOs from roster shrinkage, type-chart events. Trainer
    --tail-augment randomly truncates tails so the policy stays calibrated
    across densities.
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2026-07-14 feat(ai): decision-relevant move features (dmg_frac/kills/acc/wasted)
    Skill probe showed the model masters exactly the skills the tokenizer
    hands it as features (type_eff -> 77% on immunity puzzles) and fails
    the ones requiring derivation from move identity (2% on redundant
    status, 5% on damage ranking). dmg_feats adds four channels on
    MY_ACTIVE move tokens: approx. L100 standard-stat damage fraction,
    guaranteed-kill flag, accuracy, and wasted-move flag (status vs
    statused/immune target, heal at full HP). Flag-gated; old checkpoints
    unaffected.
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2026-08-15 hw: retarget SoM to Octavo OSD3358-1G-ISM (1 GB DDR3L)
    Move the main SoM to OSD3358-1G-ISM: 1 GB DDR3L in a 21x21 mm 256-BGA,
    1.27 mm pitch, with integrated PMIC. PocketBeagle is the reference design.
    - Add Pokeboy.pretty/OSD335X-BGA-256.kicad_mod, adapted from the
    BeagleBoard.org PocketBeagle design (CC BY 4.0); attribution in
    hardware/pokeboy-hw/THIRD_PARTY_NOTICES.md.
    - Update schematic, PCB, Core1106 symbol, and the :6767 preview
    renders/FAB_NOTES for the new part.
    - Drop the stale PROTO-A fabrication/gerber/source zips. They describe
    the superseded revision and must not be fabricated.
    Status: PROTO-B, DFM HOLD. DRC shows no shorts or spacing violations but
    still reports 15 unc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
    [pokeboy-hw.kicad_pcb, pokeboy-hw.kicad_sch]
2026-08-15 hw: add PCBWay quotation package for PROTO-B (DFM HOLD)
    Manufacturing handoff for the OSD3358-1G-ISM revision, generated from the
    KiCad source in the parent commit.
    - BOM.csv: grouped exact MPNs and per-board quantities. Switch families
    are fixed at 4x EVQ-P1905M, 2x B3AL-1001P, 2x EVQ-P2B02B; no
    substitution without written approval (force and travel are deliberate).
    - CPL.csv: KiCad centroid export in mm; PCBWay applies its own KiCad
    rotation convention during DFM review.
    - PCB_SPEC.csv: order-form values (4 layer, 0.80 mm, 1 oz/0.5 oz, ENIG,
    black mask, 0.10/0.10 mm, 0.45/0.20 mm vias, IPC Class 2).
    - DFM_DRC_REPORT.txt: authoritative hold list.
    - README.md: release gate and asse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
    [BOM.csv, PCB_SPEC.csv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]
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2026-08-15 hw: reroute LCD_D1_CORE out of the RN10 pad gap - DRC now clean
    The last unconnected item was RN10 pad 3, the SYSBOOT pull-down ground
    for LCD_D2_CORE. Its F.Cu pour island had no room for a stitching via:
    the island is walled by the LCD_D1_CORE escape at x=39.323 and the
    OSD_3V3B In2 spine at x=40.158, a 0.835 mm corridor where a 0.45 mm via
    needs 0.800 mm. Widening it eastward is blocked by the LCD_D3_CORE via
    at (40.560,24.735), and pad 3 is only 0.4 mm wide, so any via there
    protrudes past the pad.
    Fix the cause instead of the symptom. LCD_D1_CORE ran from RN10 pad 7
    south through the 0.4 mm gap between pads 2 and 3 - both GND - which is
    what pinched the pour off. Move that branch off F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
    [PCB_SPEC.csv, pokeboy-hw.kicad_pcb]
2026-08-15 hw: reconcile the schematic to the board and clean up the CPL
    The schematic did not describe this board. It still held the Luckfox
    Core1106 (Rockchip RV1106, 112 numeric pins) as U1 while the board is an
    Octavo OSD3358 BGA-256; 17 parts existed only in the PCB; 6 existed only
    in the schematic; and ERC therefore only ever covered 99 of 110 parts.
    Schematic, matching the sheet's existing style (labels on pins, no wires):
    - Replace U1 with an OSD3358_BGA256 symbol whose 132 pins are the ball
    designators the board uses. GENERATED FROM THE LAYOUT - it makes the two
    files agree, it does not verify the ball map against Octavo's datasheet.
    - Add the 17 PCB-only parts: Y1, J9, RN7-RN10, R102, R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
    [BOM.csv, pokeboy-hw.kicad_pcb, pokeboy-hw.kicad_sch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]
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2026-08-16 hw: add the PCBWay order configuration and correct the trace/space spec
    PCBWAY_ORDER.md gives a field-by-field answer for both PCBWay forms - the PCB
    instant quote and the PCBA form - with each value measured from the board rather
    than restated from the spec sheet.
    Two corrections to PCB_SPEC.csv fall out of that:
    - Minimum trace/space was recorded as 0.10 / 0.10 mm. The narrowest track
    actually routed is 0.15 mm; only 0.15 and 0.40 mm exist on the board. 0.10 mm
    was the design-rule floor, not the geometry.
    - Minimum spacing really is 0.10 mm. Tightening the clearance rule and refilling
    the zones before re-running DRC gives 0 clearance violations at 0.100 mm and
    428 at 0.127 mm, so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
    [PCB_SPEC.csv]
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2026-08-16 hw: remove dead copper - 34 dangling stubs, orphan via, isolated pour islands
    DRC warning triage (78 -> 36). Removed every dangling track stub (including a
    13 mm antenna on BAT_SENSE and 11 mm on BL_CTRL), one via on BTN_LEFT left
    hanging by the stub removal, three AUX_3V3 patch zones that were entirely
    isolated dead copper, and one patch zone whose fill was empty. The remaining
    patch zones now remove isolated islands on refill. All 36 remaining warnings
    are cosmetic silkscreen/text items plus the known Y1 library-footprint note.
    DRC: 0 errors, 0 unconnected, 36 warnings. Netlist untouched.
    [pokeboy-hw.kicad_pcb]
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2026-08-16 hw: correct the drill count in PCB_SPEC after the via removal
    227 plated hits / 221 vias, matching the regenerated drill files.
    [PCB_SPEC.csv]
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2026-08-16 hw: fix the USB dead-on-arrival findings from the Octavo checklist pass
    Self-review against Octavo's OSD335x Schematic Checklist found USB0_VBUS (J16)
    fed 2.5 V by the R3/R4 10k/10k divider - below the PHY's 4.4 V session-valid
    threshold, so USB device mode and USB boot recovery could never work. The ball
    is 5 V-tolerant and nothing else uses the divided net (verified: net members
    are C1, R3, R4, J16 only), so R3 becomes 0R and R4 is DNP; C1 stays as a
    filter. R1/R2 22R series resistors on USB0 DP/DM are prohibited by the same
    checklist (the PHY terminates internally) and become 0R links.
    Value/DNP changes only - no copper moved. DRC 0 errors, ERC unchanged,
    CPL regenerated (100 placements,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
    [BOM.csv, pokeboy-hw.kicad_pcb, pokeboy-hw.kicad_sch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]
2026-08-16 hw: sync the fabrication zip and placement count after the USB fixes
    The previous commit's zip update ran against stale staging copies (relative-
    path trap, section 10 of the handover earns its keep). The zip now carries the
    real BOM/CPL/PCB_SPEC, verified byte-identical, and PCB_SPEC records 100
    placements / 3 DNP.
    [PCB_SPEC.csv]
2026-08-16 hw: close the Octavo checklist copper items
    - SYS_VOUT bulk (PD4, was mandatory-and-missing): C107-C109, three 22 uF 0402
    (same GRM155R61A226ME11D as C7/C8, 66 uF nominal to survive DC-bias derating)
    placed below U1 at y=9.7, fed by a 0.3 mm F.Cu trunk down the col-6/7 ball
    gap from the existing SYS_VOUT interlink; GND pads land in the F.Cu pour.
    - VIN_BAT (P8/R8/T8) strapped to PMIC_BAT_SENSE (N7) as new net /VIN_BAT;
    VIN_USB (P9/R9/T9) tied to GND via the N9 ball - Table 13 Use Case 4.
    - EEPROM_WP (M2) tied to GND.
    - 12 GND stitching vias added beside DGND balls under U1 (was 2 in the whole
    field), each collision-checked on all four layers; drill 227 -> 239 hits.
    - U1's schematic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
    [BOM.csv, PCB_SPEC.csv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]
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2026-08-18 PROTO-B1: fix all design-review findings, DRC/ERC clean
    Design review (2026-08-18) found the PROTO-B package unbuildable. All
    findings fixed and verified; full record in
    hardware/manufacturing/pcbway/OPEN_DESIGN_ISSUES.md.
    - U7: TPD2EUSB30DRTR was on a SOT-23-3 land; now Texas_DRT-3, pocket
    re-routed (D+ to In1 below pad 1, D- via In1 spine)
    - USB: R1/R2 0R jumpers removed; USB_DP/USB_DM one continuous net per
    leg J1 -> U7 -> U1; stale stubs and redundant vias deleted
    - J5: exclude_from_pos_files removed so the WF030-39S FFC connector is
    actually placed (CPL 102 placements); BOM row split connector/panel;
    pin 35 IM3 strap GND -> AUX_3V3 per EA TFT020-23AI RGB mode
    - BQ24074: EN1 str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
    [BOM.csv, PCB_SPEC.csv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]
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2026-08-19 Fix stale counts after R1/R2 deletion
    BOM row 34 still listed deleted R1/R2 (now R3 only, qty 1); placement
    counts corrected everywhere to 102 placements / 111 footprints / 6
    pad-only (were 103/113/7 from before the PROTO-B1 changes). Gerbers
    zip repacked for the LAYERS.txt count fix; gerber/drill layers
    byte-identical.
    [BOM.csv, PCB_SPEC.csv]
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
